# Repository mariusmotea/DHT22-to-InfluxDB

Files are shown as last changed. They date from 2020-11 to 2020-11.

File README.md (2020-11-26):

# DHT22-to-InfluxDB
Temperature and humudity logger to InfluxDB using basic circuit with esp8266 and DTH22

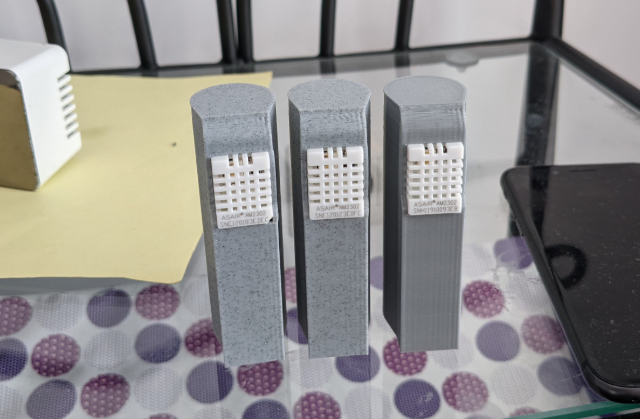
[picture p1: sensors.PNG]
sensors


### Requirements

 - free InfluDB Cloud account
 - Arduino IDE
 - 1 x ESP-M2 module
 - 1 x DHT22 sensor
 - 1 x 20700 Li battery
 - 1 x MCP1700T-3302E/TT power regulator
 - 1 x 320k SMD resistor (or 100K + 220k in serial)
 - 1 x 470ohm SMD resistor
 - 1 x 100k SMD resistor
 - 1 x 10k SMD resistor
 - 1 x 5k6 SMD resistor
 - 1 x 100nf SMD capacitor
 - 1 x 1uf SMD capacitor
 
### Software

In the header of this sketch you need to edit InfluxDB account credentials and the sensor name. Wifi credentials are setup using WiFi Manager (https://github.com/tzapu/WiFiManager). On first power on the device will remain ~1 minute alive in order to allow debug and firmware upgrades (using /update path), after this the device will go in deep sleep and will wake up every 5 minutes in order to measure and send the data to InfluxDB. ESP-M2 is based on esp8285 and has only 1MB of flash, in order to allow firmware updates select `Flash size 1MB, FS: none, OTA: 502KB`.
 
### The circuit

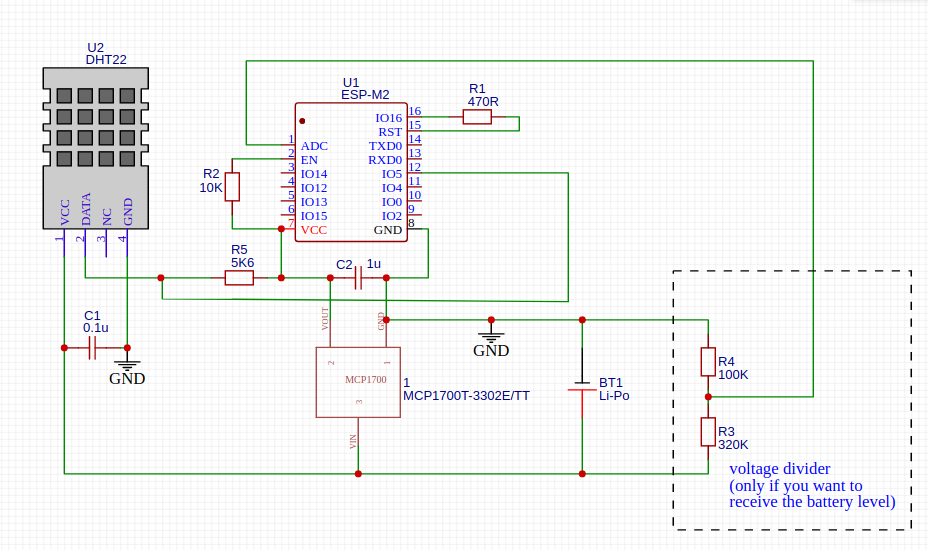
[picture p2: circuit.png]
circuit


All components except the two resistors used for voltage divider are mandatory. The DHT22 need to be powered directly from the battery for stability, otherwise it will fail to measure during esp wake-up from deep sleep. I solder all components directly on the modules as you can see in below image:

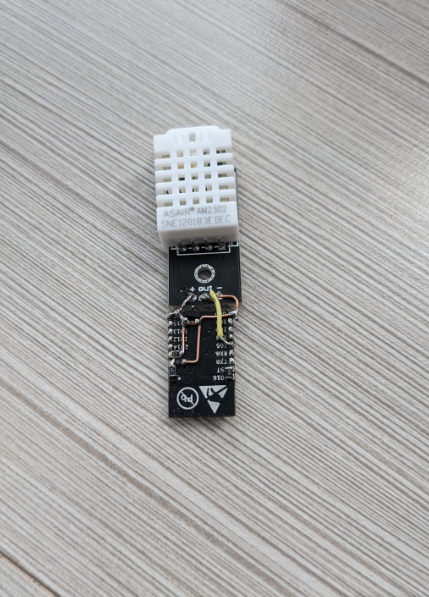
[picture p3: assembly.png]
assembly


### The case

Print the case using 0.2mm layer height with the body rotated 180 degree (the top on the printer bed) and support enabled everywhere for the DHT22 hole.

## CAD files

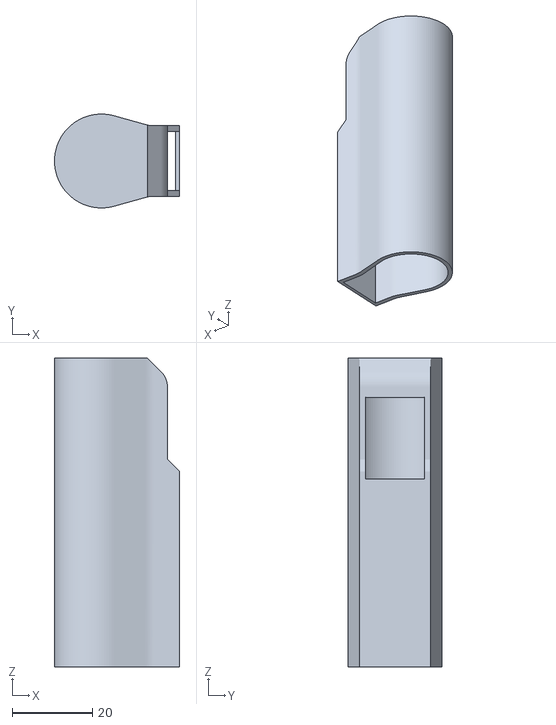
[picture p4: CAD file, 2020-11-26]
body.stl
31.2 x 23.4 x 77.0

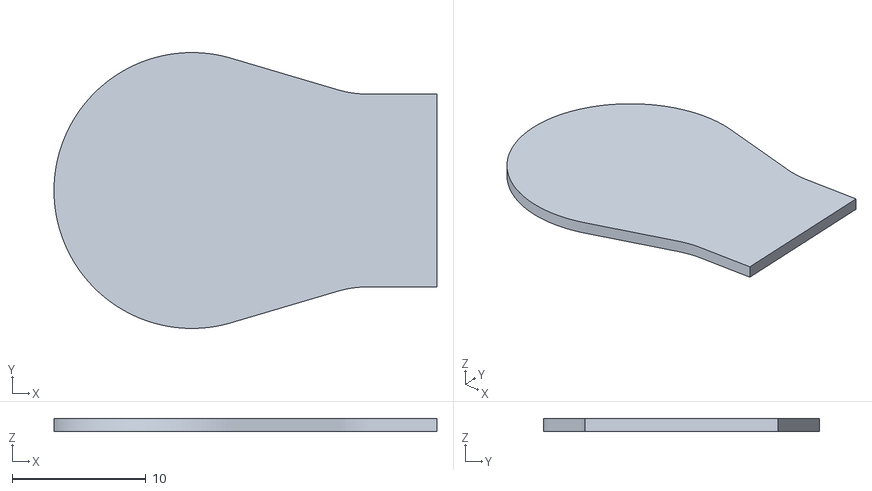
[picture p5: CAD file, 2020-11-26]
cover.stl
28.6 x 20.6 x 1.00

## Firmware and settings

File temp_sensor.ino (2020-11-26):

#include <FS.h>
#include <ESP8266WiFi.h>
#include <ESP8266mDNS.h>
#include <WiFiUdp.h>
#include <ESP8266HTTPUpdateServer.h>
#include <ESP8266WebServer.h>
#include <WiFiManager.h>
#include <DHT.h>
#include <InfluxDbClient.h>
#include <InfluxDbCloud.h>

#define DEVICE_NAME "Temp #3"
#define DHTPIN 5     // Digital pin connected to the DHT sensor
#define DHTTYPE    DHT22     // DHT 22 (AM2302)

#define INFLUXDB_URL "https://eu-central-1-1.aws.cloud2.influxdata.com"
// InfluxDB v2 server or cloud API authentication token (Use: InfluxDB UI -> Data -> Tokens -> <select token>)
#define INFLUXDB_TOKEN "ayIsLDXI63f8bPfVqVJyxxxxxxxxxxxxxxxxxxxxxxxxxxxxxxxxxxxxxxxxxxxxqJfbNWXJJxjA3OTHVS4YbuvHow=="
// InfluxDB v2 organization id (Use: InfluxDB UI -> User -> About -> Common Ids )
#define INFLUXDB_ORG "marius.motea@example.com"
// InfluxDB v2 bucket name (Use: InfluxDB UI ->  Data -> Buckets)
#define INFLUXDB_BUCKET "marius.motea's Bucket"


int counter;
// current temperature & humidity, updated in loop()
float t = 0.0;
float h = 0.0;
float Vin = 0.00;
int val = 0;

// Set timezone string according to https://www.gnu.org/software/libc/manual/html_node/TZ-Variable.html
// Examples:
//  Pacific Time: "PST8PDT"
//  Eastern: "EST5EDT"
//  Japanesse: "JST-9"
//  Central Europe: "CET-1CEST,M3.5.0,M10.5.0/3"
#define TZ_INFO "CET-1CEST,M3.5.0,M10.5.0/3"

// InfluxDB client instance with preconfigured InfluxCloud certificate
InfluxDBClient client(INFLUXDB_URL, INFLUXDB_ORG, INFLUXDB_BUCKET, INFLUXDB_TOKEN, InfluxDbCloud2CACert);

extern "C" {
#include "user_interface.h"
}

ESP8266WebServer server(80);
ESP8266HTTPUpdateServer httpUpdateServer;
DHT dht(DHTPIN, DHTTYPE);


void goingToSleep() {
  yield();
  delay(100);
  ESP.deepSleep(300e6); //every 300 seconds => 5 minutes
  yield();
  delay(100);
}


void readSensor() {
  t = dht.readTemperature();
  // Read temperature as Fahrenheit (isFahrenheit = true)
  //float newT = dht.readTemperature(true);
  // if temperature read failed, don't change t value
  if (isnan(t)) {
    delay(50);
    t = dht.readTemperature();
  }
  // Read Humidity
  h = dht.readHumidity();
  if (isnan(h)) {
    delay(50);
    h = dht.readHumidity();
  }
}

// Data point
Point sensor("DHT22");

void setup()  {
  dht.begin();
  delay(500);
  WiFi.mode(WIFI_STA);
  pinMode(A0, INPUT); //assigning the input port
  WiFiManager wifiManager;
  wifiManager.setConfigPortalTimeout(120);
  wifiManager.autoConnect("TempSensor");

  rst_info *rinfo;
  rinfo = ESP.getResetInfoPtr();

  if ((*rinfo).reason != REASON_DEEP_SLEEP_AWAKE) {

    httpUpdateServer.setup(&server);

    server.on("/", []() {
      val = analogRead(A0);//reads the analog input
      Vin = (val * 4.2) / 1024.00;
      readSensor();
      server.send(200, "text/plain", "Umiditate " + String(h) + "%, Temp " + String(t) + ", Bat " + String(Vin) + "V");
    });

    server.begin();
  } else {
    val = analogRead(A0);//reads the analog input
    Vin = (val * 4.2) / 1024.00;
    readSensor();
    sensor.addTag("device", DEVICE_NAME);
    sensor.addField("temp", t);
    sensor.addField("hum", h);
    sensor.addField("bat", Vin);
    client.writePoint(sensor);
    goingToSleep();
    delay(10000);

  }
}

void loop() {
  server.handleClient();
  delay(20);
  counter++;
  if (counter == 5000) {
    goingToSleep();
  }
}
